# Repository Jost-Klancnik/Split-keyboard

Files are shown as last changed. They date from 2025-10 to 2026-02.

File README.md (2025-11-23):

# Split Mehanska Tipkovnica

To je repozitorij za razvoj moje lastne "split" ergonomske mehanske tipkovnice, namenjene programrjem, od zasnove do končnega izdelka.

## O Projektu
Gre za razvoj lastne žične "split" tipkovnice, ki bo delovala z dvema Pro Micro krmilnikoma. Polovici bosta med seboj povezani preko TRRS kabla, "master" stran pa bo z računalnikom povezana preko USB-c-ja. Projekt temelji na odprtokodnih orodjih in bo v celoti dokumentiran v tem repozitoriju.

## Načrt Dela
Projekt je razdeljen na več faz, ki si sledijo v logičnem zaporedju. Spodaj je opisan časovni potek in uporabljena orodja.

### Faza 1: Dizajn in Načrtovanje PCB (Zaključeno)
*   **1.1 - Generiranje postavitve (Ergogen):**
    *   **Opis:** Z orodjem [Ergogen](https://ergogen.xyz/) sem na podlagi YAML konfiguracije definiral fizično postavitev tipk, obliko ohišja (plate) in pozicije za vijake.
    *   **Namen:** Ergogen omogoča hitro in parametrično prototipiranje različnih postavitev, kar je bistveno pospešilo iskanje idealne oblike, prav tako pa omogoča enostavno generiranje celotnega vezja, ko smo enkrat zadovoljni s postavitvijo.
    *   **Časovni okvir:** ~8 ur

*   **1.2 - Električni načrt in "Routing" (KiCad):**
    *   **Opis:** Generirane datoteke iz Ergogena sem uvozil v [KiCad](https://www.kicad.org/), kjer sem dokončal električno shemo. To je vključevalo dodajanje Pro Micro krmilnikov, TRRS priključkov, diod (1N4148) in matrike stikal. Nato sem ročno povezal vse komponente ("routing").
    *   **Namen:** KiCad je standard v svetu odprtokodne elektronike in omogoča popoln nadzor nad dizajnom tiskanega vezja (PCB).
    *   **Časovni okvir:** ~10 ur

### Faza 2: Naročilo in Sestavljanje (Naslednji koraki)
*   **2.1 - Izdelava PCB in nabava komponent:**
    *   **Opis:** Iz KiCada bom izvozil Gerber datoteke in jih poslal v izdelavo pri [JLCPCB](https://jlcpcb.com/). Hkrati bom naročil vse potrebne elektronske komponente (stikala, diode, TRRS konektorji, Pro Micro itd.) preko [AliExpressa](https://www.aliexpress.com/).
    *   **Časovni okvir:** ~2-4 tedne (čakanje na dostavo)

*   **2.2 - Spajkanje in montaža:**
    *   **Opis:** Ko prispejo vse komponente, sledi spajkanje diod, TRRS priključkov in Pro Micro krmilnikov na PCB. Na koncu sledi montaža stikal in ohišja.
    *   **Časovni okvir:** trenutno neznan

### Faza 3: Firmware (QMK)
*   **3.1 - Razvoj in konfiguracija:**
    *   **Opis:** Uporabil bom [QMK Firmware](https://qmk.fm/), ki je odprtokodni standard za programsko opremo tipkovnic. Potrebno bo ustvariti novo tipkovnico znotraj QMK, definirati matriko, pine na Pro Micro krmilnikih in nastaviti komunikacijo med obema polovicama.
    *   **Namen:** QMK ponuja izjemno fleksibilnost, podporo za "split" tipkovnice, več plasti (layers), makre in druge napredne funkcije.
    *   **Časovni okvir:** ~10 ur

*   **3.2 - Nalaganje Firmware-a:**
    *   **Opis:** Pripravljen firmware bom s pomočjo QMK Toolboxa ali preko ukazne vrstice naložil ("flashal") na oba Pro Micro krmilnika.

### Faza 4: Prihodnji razvoj
*   **4.1 - Razvoj konfiguracijske aplikacije:**
    *   **Opis:** V prihodnosti načrtujem razvoj lastne aplikacije (verjetno v Pythonu ali z uporabo spletnih tehnologij), ki bi omogočala spreminjanje postavitve tipk (keymap) v realnem času, brez potrebe po ponovnem nalaganju celotnega firmware-a.

## Infrastruktura in Namestitev

Za razvoj projekta so potrebna določena orodja. Spodaj so navodila za namestitev na različnih operacijskih sistemih.

### Osnovne predpogoji
Pred namestitvijo specifičnih orodij se prepričajte, da imate na sistemu nameščene:
*   **Git:** Za upravljanje z repozitorijem.
*   **Python (verzija 3.8 ali novejša) in Pip:** Potrebno za QMK.
*   **Node.js in NPM:** Potrebno za Ergogen.

---

### Namestitev na Arch Linux
*   **Vsa orodja (All-in-one):**
    ```bash
    # Git, Python, Pip, NodeJS, NPM in osnovna orodja za gradnjo
    sudo pacman -S git python-pip nodejs npm base-devel

    # KiCad
    sudo pacman -S kicad kicad-library kicad-library-3d
    ```
*   **Specifična orodja (po korakih):**
    ```bash
    # Ergogen
    npm install -g ergogen

    # QMK CLI
    pip install qmk
    qmk setup # Sledi navodilom za namestitev odvisnosti
    ```

---

### Namestitev na Windows
*   **Osnovna orodja:**
    *   **Git:** Prenesite in namestite [Git for Windows](https://git-scm.com/download/win).
    *   **Python:** Prenesite in namestite s [python.org](https://www.python.org/downloads/). 
    *   **Node.js:** Prenesite in namestite z [nodejs.org](https://nodejs.org/en/download/).
*   **Specifična orodja:**
    *   **KiCad:** Prenesite in namestite z [uradne strani KiCad](https://www.kicad.org/download/).
    *   **Ergogen & QMK:** Zaženite **Command Prompt** ali **PowerShell** in vpišite ukaze:
        ```powershell
        # Ergogen (preko NPM)
        npm install -g ergogen

        # QMK (preko Pip)
        pip install qmk
        qmk setup
        ```

---

### Namestitev na macOS
*   **Osnovna orodja (preko Homebrew):**
    *   Najprej namestite [Homebrew](https://brew.sh/), če ga še nimate.
    ```bash
    # Git, Python in Node.js
    brew install git python node
    ```
*   **Specifična orodja:**
    *   **KiCad:**
        ```bash
        brew install --cask kicad
        ```
    *   **Ergogen & QMK:**
        ```bash
        # Ergogen (preko NPM)
        npm install -g ergogen

        # QMK (preko Pip)
        pip3 install qmk # Uporabite pip3, da se izognete konfliktu s sistemskim Pythonom
        qmk setup # Sledi navodilom v terminalu
        ```

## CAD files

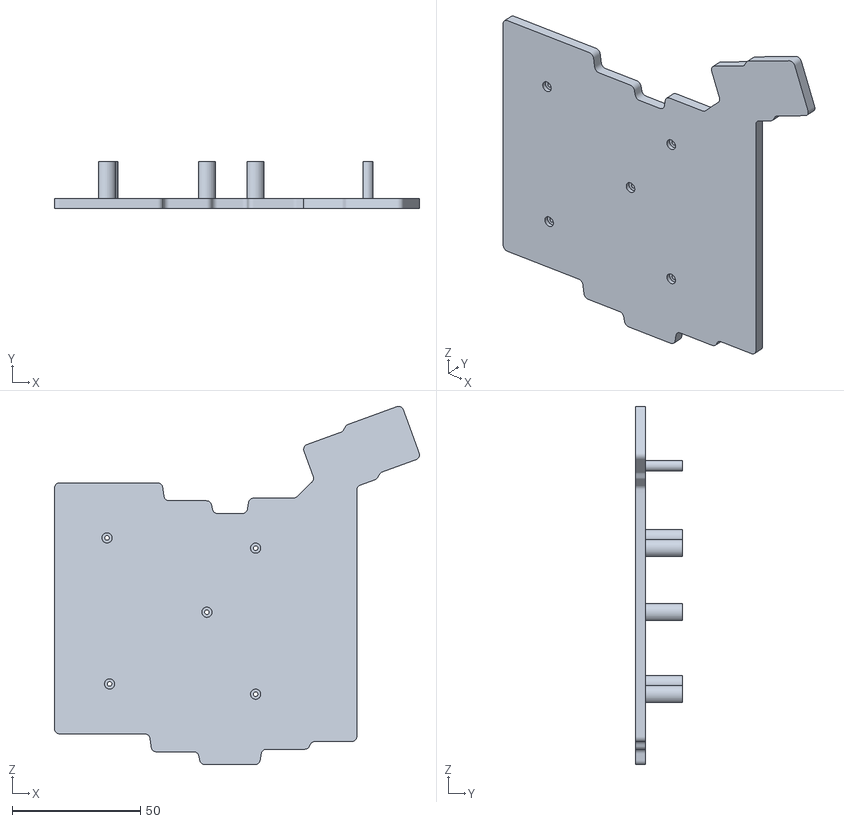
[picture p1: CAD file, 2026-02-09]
Cases/case_bottom_left_v1.STL
142.5 x 18.4 x 139.8

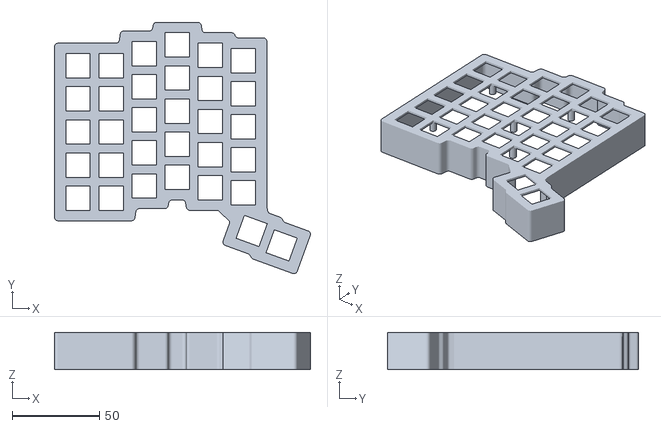
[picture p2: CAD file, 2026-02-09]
Ergogen/output/cases/case_top_left_finished.stl
147.0 x 144.4 x 21.5

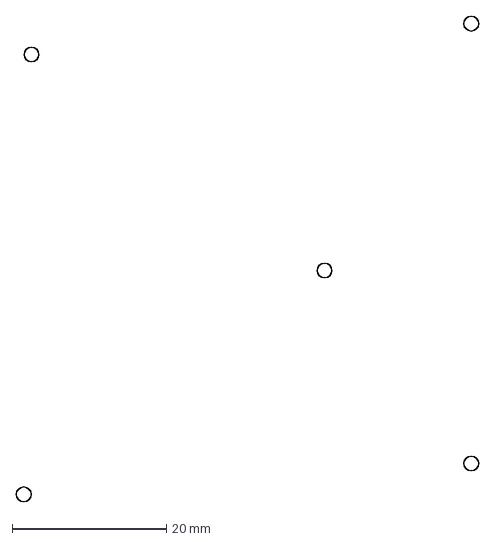
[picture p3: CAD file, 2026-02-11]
Ergogen/output/outlines/standoffs_left_xs.dxf
59.9 x 62.9 mm

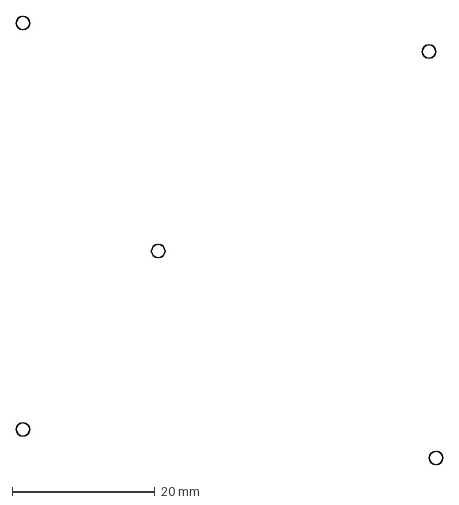
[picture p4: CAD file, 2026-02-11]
Ergogen/output/outlines/standoffs_right_xs.dxf
59.9 x 62.9 mm

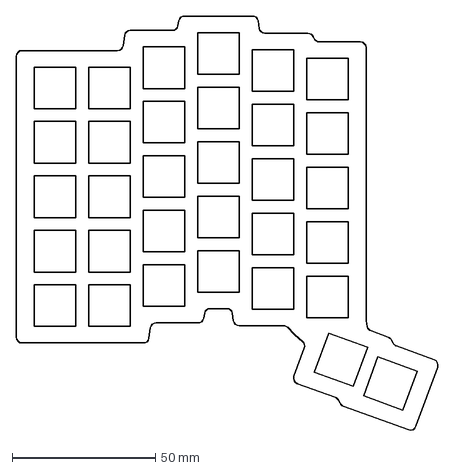
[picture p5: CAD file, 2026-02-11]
Ergogen/output/outlines/board_left_xl_cutouts.dxf
147.3 x 144.7 mm

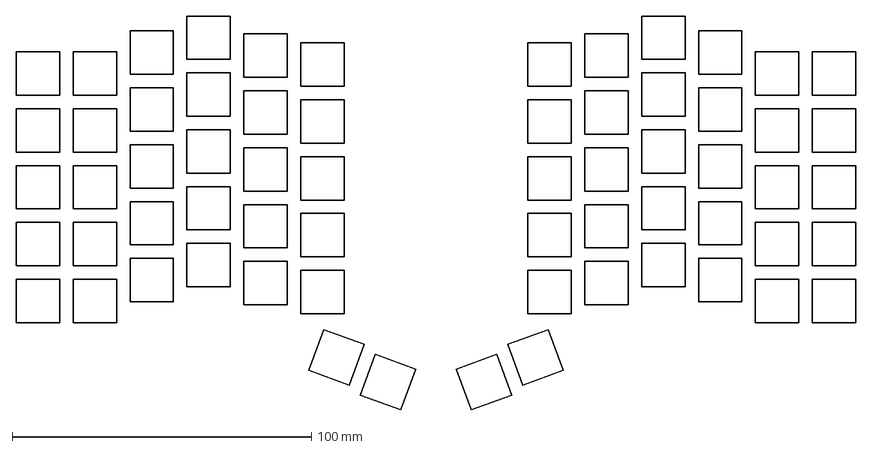
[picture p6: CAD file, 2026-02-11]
Ergogen/output/outlines/keys.dxf
280.5 x 131.7 mm

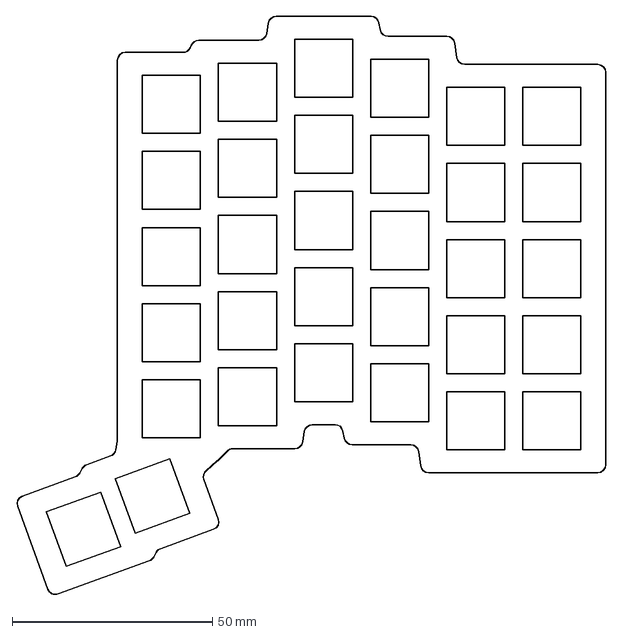
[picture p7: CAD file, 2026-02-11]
Ergogen/output/outlines/board_right_xl_cutouts.dxf
147.3 x 144.5 mm

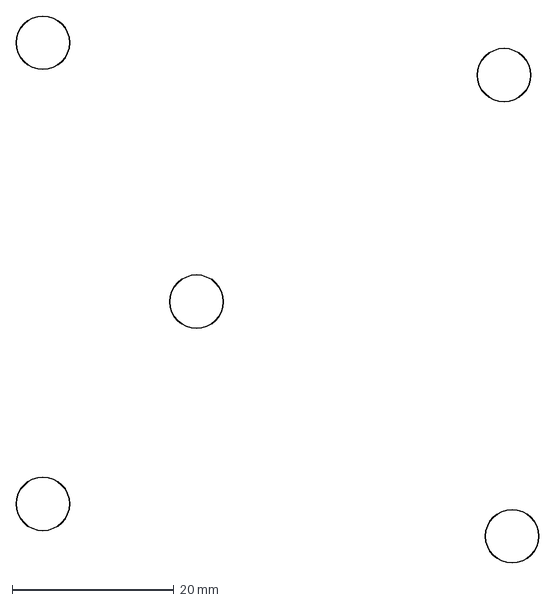
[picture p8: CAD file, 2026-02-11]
Ergogen/output/outlines/standoffs_right_xl.dxf
64.6 x 67.6 mm

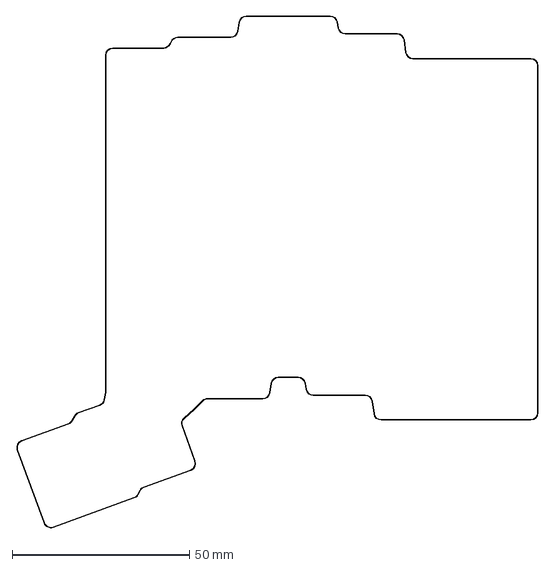
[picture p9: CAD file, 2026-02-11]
Ergogen/output/outlines/board_right_xl.dxf
147.3 x 144.5 mm

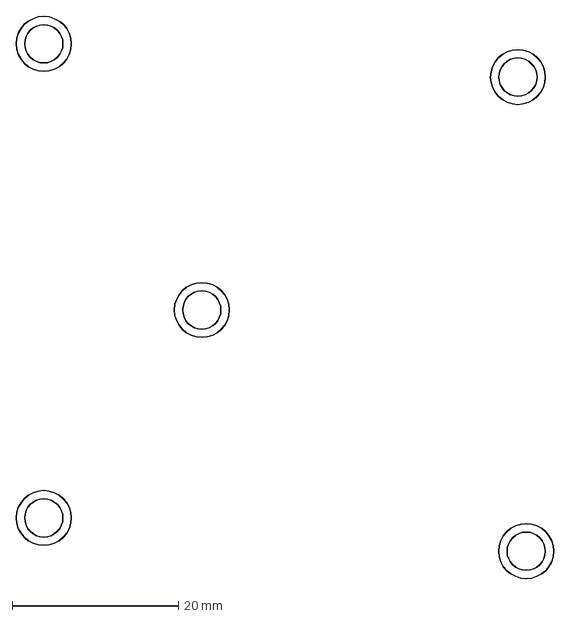
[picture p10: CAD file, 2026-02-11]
Ergogen/output/outlines/standoffs_bottom_right.dxf
64.6 x 67.6 mm

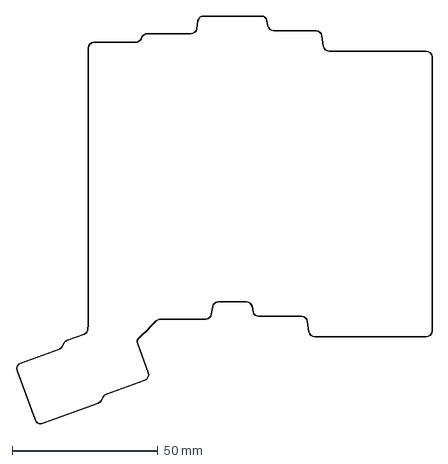
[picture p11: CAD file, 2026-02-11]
Ergogen/output/outlines/board_right_l.dxf
142.7 x 139.9 mm

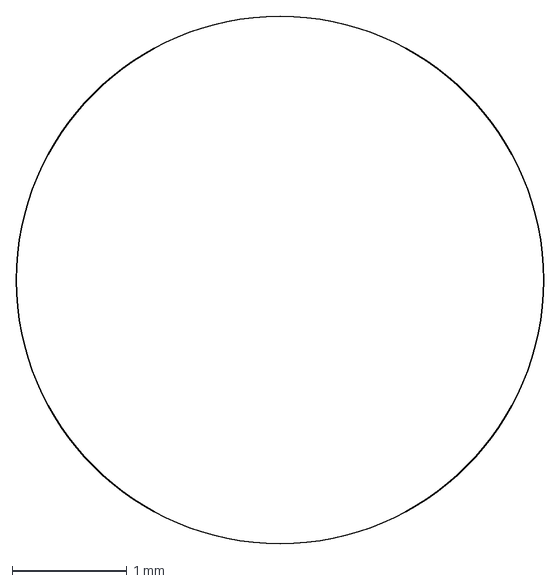
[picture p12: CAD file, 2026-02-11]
Ergogen/output/outlines/standoffs_right_bottom_thumbs.dxf
4.60 x 4.60 mm

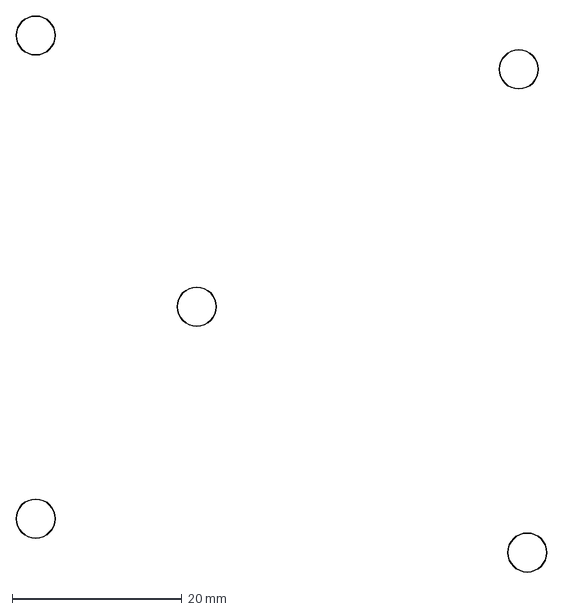
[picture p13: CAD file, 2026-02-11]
Ergogen/output/outlines/standoffs_right_m.dxf
62.6 x 65.6 mm

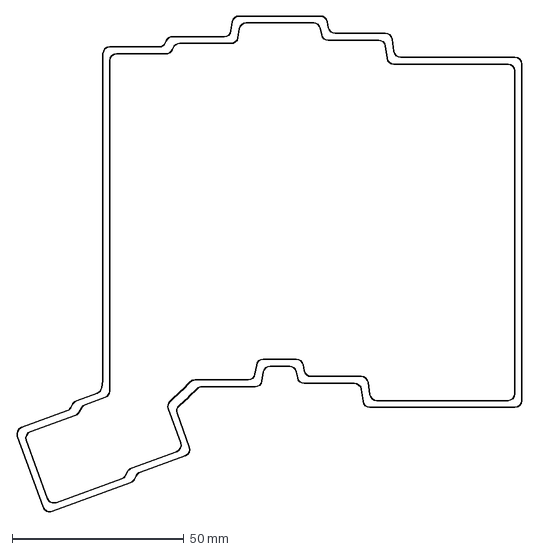
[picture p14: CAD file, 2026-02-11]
Ergogen/output/outlines/walls_right.dxf
147.3 x 144.5 mm

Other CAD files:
Cases/case_top_right_v1.STL
Ergogen/output/cases/case_bottom_left_finished.stl
Ergogen/output/outlines/standoffs_right.dxf
Ergogen/output/outlines/walls_standoffs_left.dxf
Ergogen/output/outlines/board_left.dxf
Ergogen/output/outlines/board_left_l.dxf
Ergogen/output/outlines/board_left_xl.dxf
Ergogen/output/outlines/board_right.dxf
Ergogen/output/outlines/plate_bottom_left_screw_head_part.dxf
Ergogen/output/outlines/plate_bottom_left_screw_part.dxf
Ergogen/output/outlines/plate_bottom_right_screw_head_part.dxf
Ergogen/output/outlines/plate_bottom_right_screw_part.dxf
Ergogen/output/outlines/standoffs_bottom_left.dxf
Ergogen/output/outlines/standoffs_left.dxf
Ergogen/output/outlines/standoffs_left_bottom.dxf
Ergogen/output/outlines/standoffs_left_bottom_thumbs.dxf
Ergogen/output/outlines/standoffs_left_m.dxf
Ergogen/output/outlines/standoffs_left_xl.dxf
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

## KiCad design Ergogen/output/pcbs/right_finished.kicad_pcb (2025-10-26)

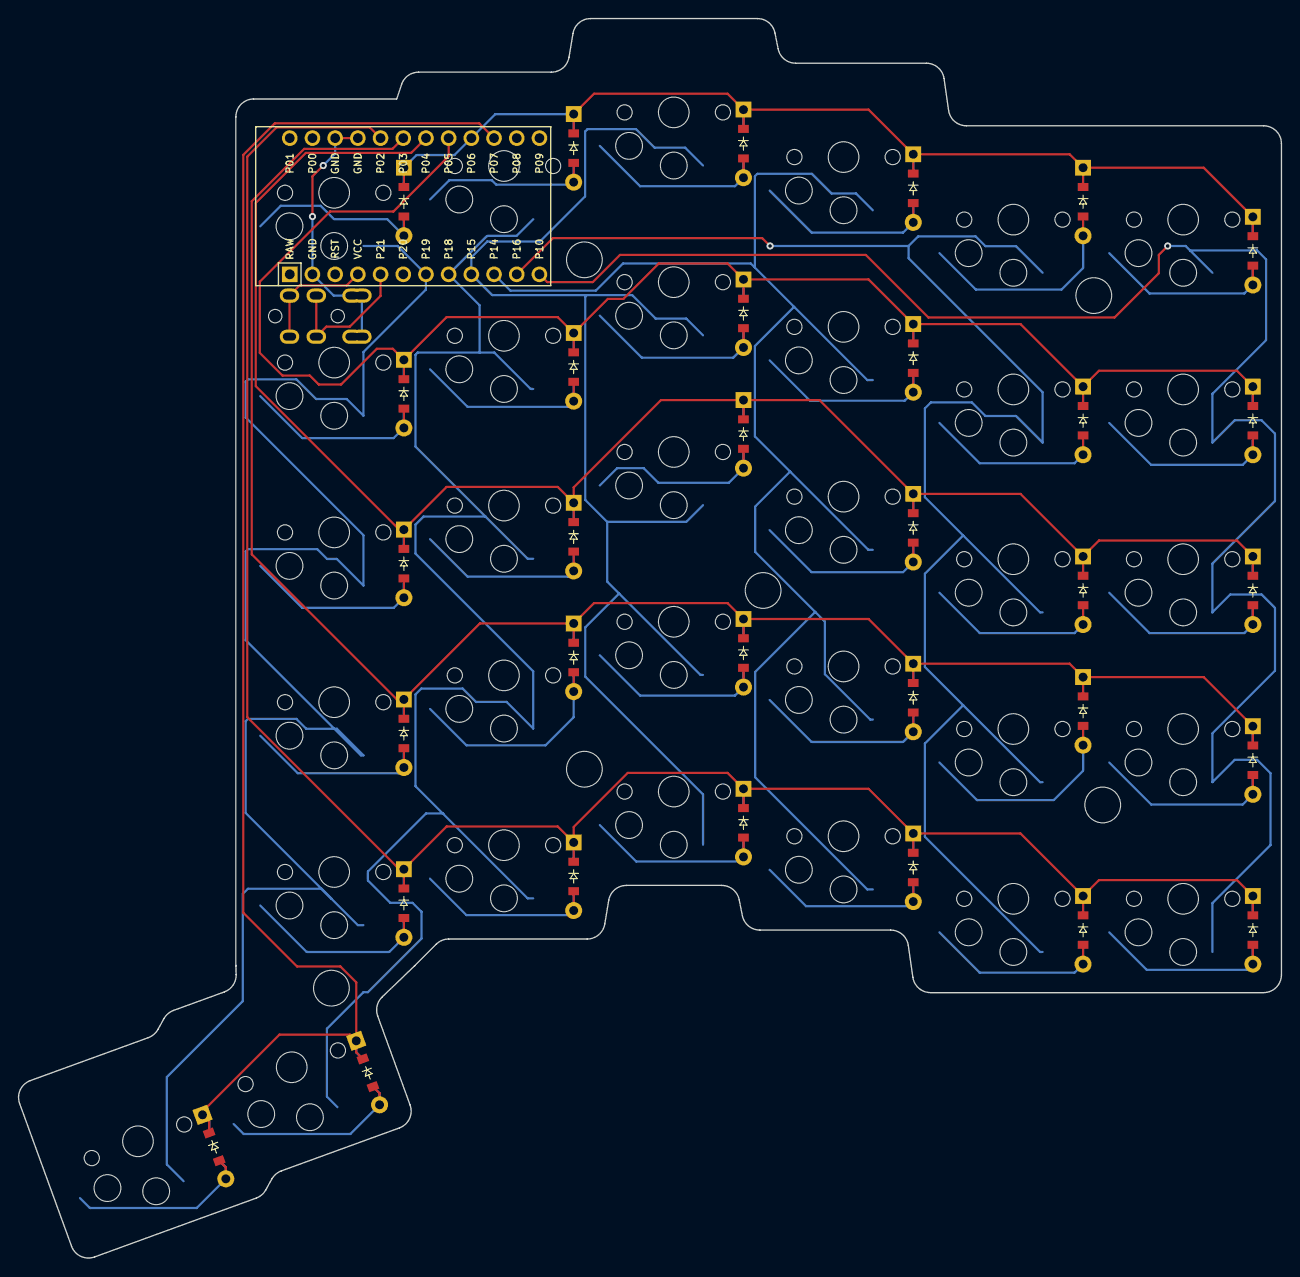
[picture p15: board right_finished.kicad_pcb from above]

Board: 2 copper layers, 141.3 x 138.7 mm, 66 parts (0 on the bottom side), 47 nets.

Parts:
D1, D2, D3, D4, D5, D6, D7, D8, D9, D10, D11, D12, D13, D14, D15, D16, D17, D18, D19, D20, D21, D22, D23, D24, D25, D26, D27, D28, D29, D30, D31, D32: ComboDiode
MCU1: ProMicro
S1, S2, S3, S4, S5, S6, S7, S8, S9, S10, S11, S12, S13, S14, S15, S16, S17, S18, S19, S20, S21, S22, S23, S24, S25, S26, S27, S28, S29, S30, S31, S32: PG1350
TRRS1: TRRS-PJ-320A-dual

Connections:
GND: MCU1.2, MCU1.15, MCU1.16, TRRS1.1, TRRS1.2
P2: D1.1, D6.1, D9.1, D14.1, D18.1, D21.1, MCU1.17
P3: D2.1, D10.1, D15.1, D22.1, D25.1, D28.1, MCU1.18
P4: D3.1, D7.1, D11.1, D19.1, D23.1, D27.1, MCU1.19
P5: D4.1, D8.1, D12.1, D16.1, D20.1, D24.1, MCU1.20
P6: D5.1, D13.1, D17.1, D26.1, D29.1, D30.1, MCU1.21
P7: D31.1, D32.1, MCU1.22
P10: MCU1.12, S1.1, S2.1, S3.1, S4.1, S5.1
P14: MCU1.10, S11.1, S12.1, S13.1, S14.1, S15.1
P15: MCU1.9, S16.1, S17.1, S18.1, S19.1, S20.1
P16: MCU1.11, S6.1, S7.1, S8.1, S9.1, S10.1
P18: MCU1.8, S21.1, S22.1, S23.1, S24.1, S25.1, S31.1
P19: MCU1.7, S26.1, S27.1, S28.1, S29.1, S30.1, S32.1
P21: MCU1.5, TRRS1.3
VCC: MCU1.4, TRRS1.4
mirror_fifth_bottom: D28.2, S22.2
mirror_fifth_home: D19.2, S23.2
mirror_fifth_mod: D18.2, S21.2
mirror_fifth_num: D29.2, S25.2
mirror_fifth_top: D20.2, S24.2
mirror_first_bottom: D2.2, S2.2
mirror_first_home: D3.2, S3.2
mirror_first_mod: D1.2, S1.2
mirror_first_num: D5.2, S5.2
mirror_first_top: D4.2, S4.2
mirror_fourth_bottom: D15.2, S17.2
mirror_fourth_home: D27.2, S18.2
mirror_fourth_mod: D14.2, S16.2
mirror_fourth_num: D17.2, S20.2
mirror_fourth_top: D16.2, S19.2
mirror_second_bottom: D25.2, S7.2
mirror_second_home: D7.2, S8.2
mirror_second_mod: D6.2, S6.2
mirror_second_num: D26.2, S10.2
mirror_second_top: D8.2, S9.2
mirror_sixth_bottom: D22.2, S27.2
mirror_sixth_home: D23.2, S28.2
mirror_sixth_mod: D21.2, S26.2
mirror_sixth_num: D30.2, S30.2
mirror_sixth_top: D24.2, S29.2
mirror_t1_thumb: D31.2, S31.2
mirror_t2_thumb: D32.2, S32.2
mirror_third_bottom: D10.2, S12.2
mirror_third_home: D11.2, S13.2
mirror_third_mod: D9.2, S11.2
mirror_third_num: D13.2, S15.2
mirror_third_top: D12.2, S14.2

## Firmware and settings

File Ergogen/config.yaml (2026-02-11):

meta:
  name: split_6x5_with_thumbs
  version: 1.0
  author: jost

units:
  px: cx + 2
  py: cy + 2

  pushX: (cx / 2)
  pushY: (cy / 2)

  padX: pushX + 2
  padY: pushY + 2

  pad: 2

  spacing: 0.75

  caseBorder: 2.5
  caseBorderInner: 0.5

  u: 19

points:
  zones:
    matrix:
      anchor:
        shift: [0, 0]   # po potrebi spremeni, da lepo centruješ
      columns:
        first:
          key:
            stagger: 0
            column_net: P10
        second:
          key:
            stagger: 0
            column_net: P16
        third:
          key:
            stagger: 7
            column_net: P14
        fourth:
          key:
            stagger: 5
            column_net: P15
        fifth:
          key:
            stagger: -6
            column_net: P18
        sixth:
          key:
            stagger: -3
            column_net: P19
      rows:
        mod:
          row_net: P2
        bottom:
          row_net: P3
        home:
          row_net: P4
        top:
          row_net: P5
        num:
          row_net: P6

    thumbs:
      anchor:
        ref: matrix_sixth_mod   # začetek thumb clusterja
        shift: [0.25u, -1.15u]
      columns:
        t1:
          key:
            splay: -20
            spread: u
            column_net: P18
          rows:
            thumb: {row_net: P7}
        t2:
          key:
            spread: u
            shift: [0, -0.1u]
            column_net: P19
          rows:
            thumb: {row_net: P7}

  mirror:
    ref: matrix_third_home
    distance: 10u

outlines:
  keys:
    - what: rectangle
      where: true
      size: [14.5, 14.5]
      fillet: 0

  board_left:
    - what: polygon
      operation: stack
      fillet: 2
      points:
        # Top
        - ref: matrix_first_num
          shift: [-padX, padY]
        - ref: matrix_second_num
          shift: [pushX - pad, padY]
        - ref: matrix_third_num
          shift: [-pushX - pad, padY]
        - ref: matrix_third_num
          shift: [pushX - pad, padY]
        - ref: matrix_fourth_num
          shift: [-pushX - pad, padY]
        - ref: matrix_fourth_num
          shift: [padX, padY]
        - ref: matrix_fifth_num
          shift: [-pushX + pad, padY]
        - ref: matrix_fifth_num
          shift: [padX, padY]
        - ref: matrix_sixth_num
          shift: [-pushX + 2.3542486, padY]
        - ref: matrix_sixth_num
          shift: [padX, padY]

        # Spremenjeno ker more it do sredine thumbou
        - ref: matrix_sixth_mod
          shift: [padX, -padY]

        - ref: thumbs_t1_thumb
          shift: [0.25padX, padY]
        - ref: thumbs_t1_thumb
          shift: [padX, padY]
        - ref: thumbs_t2_thumb
          shift: [-pushX + 1.6pad, padY]
        - ref: thumbs_t2_thumb
          shift: [padX, padY]
        - ref: thumbs_t2_thumb
          shift: [padX, -padY]
        - ref: thumbs_t2_thumb
          shift: [-padX, -padY]
        - ref: thumbs_t1_thumb
          shift: [pushX - 1.6pad, -padY]
        - ref: thumbs_t1_thumb
          shift: [-padX, -padY]
        - ref: thumbs_t1_thumb
          shift: [-padX, 0.4pushY]


        - ref: matrix_sixth_mod
          shift: [-pushX, -padY]
        - ref: matrix_fifth_mod
          shift: [pushX - pad, -padY]
        - ref: matrix_fifth_mod
          shift: [-padX, -padY]
        - ref: matrix_fourth_mod
          shift: [pushX - pad, -padY]
        - ref: matrix_fourth_mod
          shift: [-pushX + pad, -padY]
        - ref: matrix_third_mod
          shift: [pushX + pad, -padY]
        - ref: matrix_third_mod
          shift: [-pushX + pad, -padY]
        - ref: matrix_second_mod
          shift: [pushX + pad, -padY]
        - ref: matrix_second_mod
          shift: [-pushX + pad, -padY]
        - ref: matrix_first_mod
          shift: [-padX, -padY]

        # - ref: thumbs_t1_thumb
        #   shift: [-padX, -padY - 0.5u]   # levi thumb, nekoliko nižje
        # - ref: thumbs_t2_thumb
        #   shift: [padX, -padY - 0.7u]

        # Connect to top
        - ref: matrix_first_num
          shift: [-padX, -padY]
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

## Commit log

2025-10-26 Initial commit (added ergogen files)
    [board_left.dxf, board_right.dxf, keys.dxf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]
2026-02-09 Updated Ergogen files
    [board_left_l.dxf, board_left_xl.dxf, board_left_xl_cutouts.dxf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]
2026-02-09 Added .STL files for keyboard case.
    [case_bottom_left_v1.STL, case_top_right_v1.STL]
2026-02-11 Updated Ergogen config.yaml for case fixes
    [board_right_l.dxf, board_right_xl.dxf, board_right_xl_cutouts.dxf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]
2026-02-11 Changed keyholes scale from 14 to 14.5
    [board_left_xl_cutouts.dxf, board_right_xl_cutouts.dxf, keys.dxf]
2026-02-11 Made standoffs xs 0.1 bigger for 3D printing.
    [plate_bottom_left_screw_part.dxf, plate_bottom_right_screw_part.dxf, standoffs_left_xs.dxf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]
